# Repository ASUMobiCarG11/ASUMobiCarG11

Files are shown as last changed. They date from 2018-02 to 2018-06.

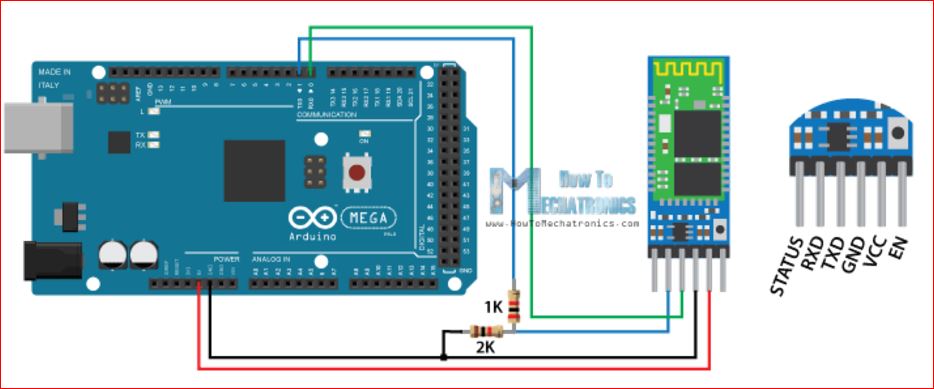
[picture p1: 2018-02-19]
bluetooth Module installation.JPG

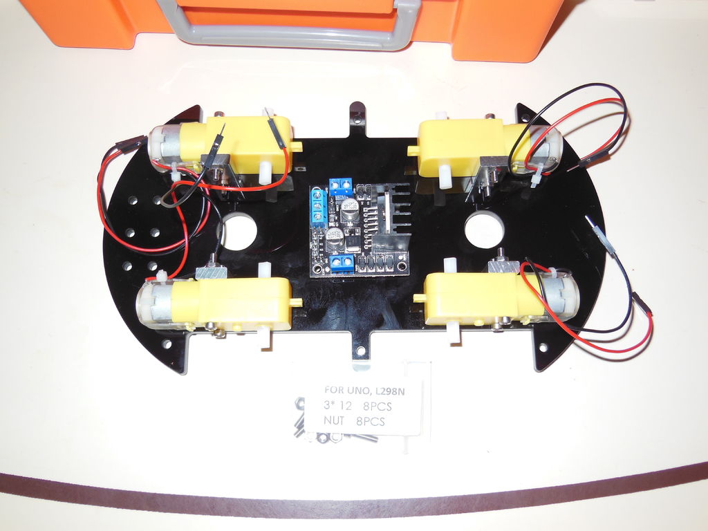
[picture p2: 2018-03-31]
Car installation step by step/installing mototr driver 1.jpg

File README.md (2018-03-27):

# ASUMobiCarG11
DESCRIPTION: 

It is required to develop a Mobile Controlled Car. The car allow easy driving with obstacles avoidance, accurate movement, line tracking.
A simple android application is used to control the car.

The project is submitted to DR/ Mohamed Sobh / Control Componenets course / Faculty of Engineering / Ain Shams Universty 

Team Members :

Omar Mohamed Ali  

Omar Nasr el Din

Omar Hesham 

Kareem Salah

Martin Joseph

Mark Youssef

Mario Hany 

Micheal Ashraf

Fatma abdelmoniem

Fayrouz Niazy 

CAR Videos :https://drive.google.com/folderview?id=14SdS284a--CmgsWrzYH-oOBZbFa_0wmK

#For Contact : 
    Github :  
    
    OmarNasrEldeen

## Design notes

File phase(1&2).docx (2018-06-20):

-project name : mobicar project

****************************************************

-the purpose:

- in our project we want to develop a Mobile Controlled Car. The car allow easy driving with obstacles avoidance, accurate movement, line tracking.

*****************************************************

-project contants:

*our project contants from 2 steps:

i.Easy Driving Application:

-Our purpose that user can control car movement (in all directions) using mobile

<Using Bluetooth module> and the car should be able to avoid obstacles <using ultrasonic>.

ii.Line Tracking Application:

-our purpose that can follow the line when it placed over the track

<using line follow sensor>

****************************************************************************

-First step in details:

We use: Arduino Uno - motor driver - Bluetooth module - body of car –

3 batteries - ultrasonic

-at first meeting : we connect motor driver with motors of the car body and connect it with

arduino according the code of arduino,we connect the Bluetooth module with arduino

,and supply all circuit with batteries . After many tries to make sure our code and our

connections, we use a Bluetooth app to control the car to make sure that it can move in

all direction according the app .

--this picture shows the all connections:

***********************************************************************************

-at second meeting : we maked sure that the previous step was Successful .and continue

our connections , connect the ultra-sonic with arduino and try to move a car , at this time

we faced our first problem which was that we find two wheel move but the other don't

move we think that was the mistake in code ,we check it step by step to discover the

mistake but we found that the code is completely correct and discovered that problem

happen when we connect all component with each other ,so we found out that problem

of supply so we recharged our batteries and try again ,we found out this problem

disappear.

--this link of the video of the car motion with avoid obstacles:

https://drive.google.com/folderview?id=14SdS284a--CmgsWrzYH-oOBZbFa_0wmK

*************************************************************************************

second step in details:

we use : all the previous components +3 line follower sensor

- At first meeting : we connect the 3 sensors with the Arduino according the code , then we make sure that all the connections are right , then we tests the code and fixed it as we found a problems with it and the line follower wasn’t working well .
- At the second meeting : we checked that the the connections and the code are working well , but we found a problem “ the places that we put the sensors on it were not making the car follow the directions well “ – so we tried to fix this and after many tries it works , and we check that the car follows the tracks well as we make tracks for it and it works well.
- At the third meeting : we prepared for the track and draw it on the 2x2m white sheets and the line thickness was 2mm , we started to work on it and put the car to follow the track , but the car went out of the track and we tried to find the problem in the car and after many tries it didn’t work , so we announce the doctor that that track thickness makes problem with the car and he tells us to work on another thickness.
- At the 4th meeting : we made the track on the new thickness and tried to test it with the car and it worked , we shot the video for the car and then we upload it .

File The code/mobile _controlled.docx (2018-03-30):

#include <AFMotor.h>

| AF_DCMotor motor1(1);
| AF_DCMotor motor2(2);
| AF_DCMotor motor3(3);
| AF_DCMotor motor4(4);
| char bt='S';
| void setup()
| {
| Serial.begin(38400);
| motor1.setSpeed(255);
| motor2.setSpeed(255);
| motor3.setSpeed(255);
| motor4.setSpeed(255);
| Stop();
| }
| void loop() {
| bt=Serial.read();
| if(bt=='F')
| {
| forward();
| }
| if(bt=='B')
| {
| backward();
| }
| if(bt=='L')
| {
| left();
| }
| if(bt=='R')
| {
| right();
| }
| if(bt=='S')
| {
| Stop();
| }
| }
| void forward()
| {
| motor1.run(FORWARD);
| motor2.run(FORWARD);
| motor3.run(FORWARD);
| motor4.run(FORWARD);
| }
| void backward()
| {
| motor1.run(BACKWARD);
| motor2.run(BACKWARD);
| motor3.run(BACKWARD);
| motor4.run(BACKWARD);
| }
| void left()
| {
| motor1.run(FORWARD);
| motor2.run(FORWARD);
| motor3.run(BACKWARD);
| motor4.run(BACKWARD);
| }
| void right()
| {
| motor1.run(BACKWARD);
| motor2.run(BACKWARD);
| motor3.run(FORWARD);
| motor4.run(FORWARD);
| }
| void Stop()
| {
| motor1.run(RELEASE);
| motor2.run(RELEASE);
| motor3.run(RELEASE);
| motor4.run(RELEASE);
| }

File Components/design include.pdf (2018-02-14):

Design i just attach in group included The following:

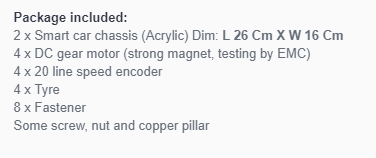
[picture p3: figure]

## PRICE :250 LE

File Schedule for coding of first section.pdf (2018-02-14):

## Schedule for coding of first section

## Schedule

Week 2 | Designing of car functionality
Week 3 | Coding of DC motors
Week 4 | Coding of ultrasonic sensor
Week 5 | Coding of servo motor
Week 6 | Testing and debugging

debugging

coding

Design

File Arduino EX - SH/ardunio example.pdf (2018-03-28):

Programming
code for
Receiver
part::
const int trigPin = 9; const int echoPin = 10; // defines variables
long duration;
int distance, Pdistance; void setup()
{
pinMode(trigPin, OUTPUT); // Sets the trigPin as an Output pinMode(echoPin, INPUT); // Sets the echoPin as an Input Serial.begin(9600); // Starts the serial communication
}
void loop()
{
Pdistance=distance;
Calc();
distance= duration*0.034;
if (Pdistance==distance || Pdistance==distance+1 || Pdistance==distance-1 )

{
Serial.print("Measured Distance: ");
Serial.println(distance/2);
}
//Serial.print("Distance: "); //Serial.println(distance/2); delay(500);
}
void Calc()
{
duration=0;
Trigger_US();
while (digitalRead(echoPin)==HIGH); delay(2);
Trigger_US();
duration = pulseIn(echoPin, HIGH); }
void Trigger_US()
{
// Fake trigger the US sensor digitalWrite(trigPin, HIGH); delayMicroseconds(10); digitalWrite(trigPin, LOW);
}
// Programming code for Transmitter part:: // defines pins numbers
const int trigPin = 9;
const int echoPin = 10; // defines variables
long duration;
int distance;
void setup()
{

pinMode(trigPin, OUTPUT); // Sets the trigPin as an Output pinMode(echoPin, INPUT); // Sets the echoPin as an Input Serial.begin(9600); // Starts the serial communication
}
void loop()
{
// Sets the trigPin on HIGH state for 10 micro seconds digitalWrite(trigPin, HIGH);
delayMicroseconds(10);
digitalWrite(trigPin, LOW); delay(2);
}

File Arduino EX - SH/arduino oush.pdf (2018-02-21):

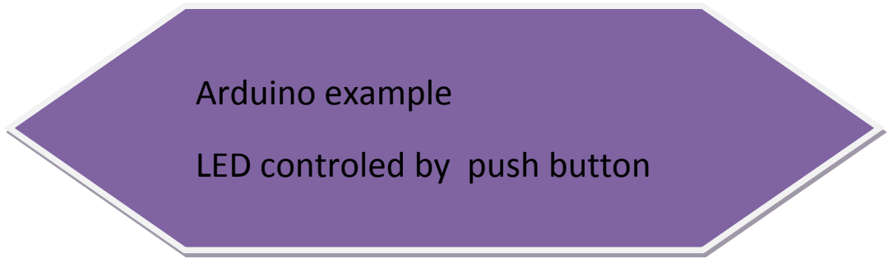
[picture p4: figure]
Arduino example; LED controled by push button
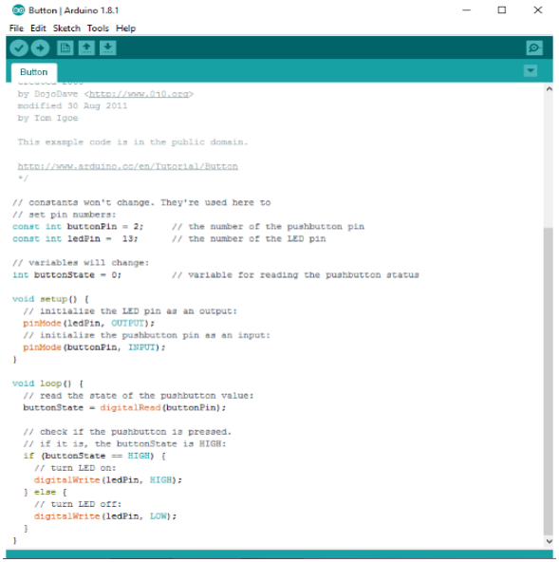
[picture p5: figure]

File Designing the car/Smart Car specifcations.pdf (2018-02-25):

# Smart Car

# ASUMobiCarG11

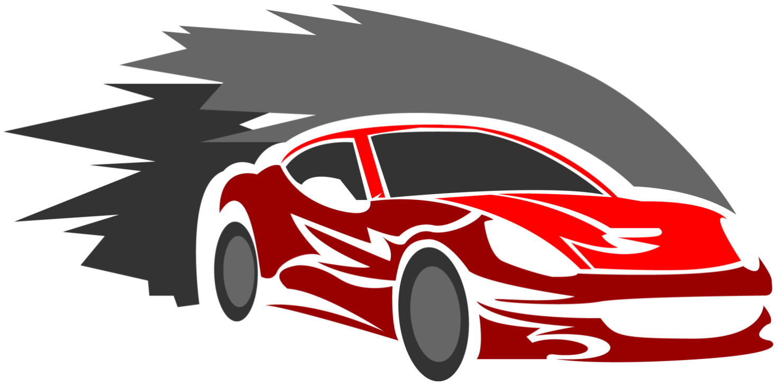
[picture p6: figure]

# It’s time to control

# Team members

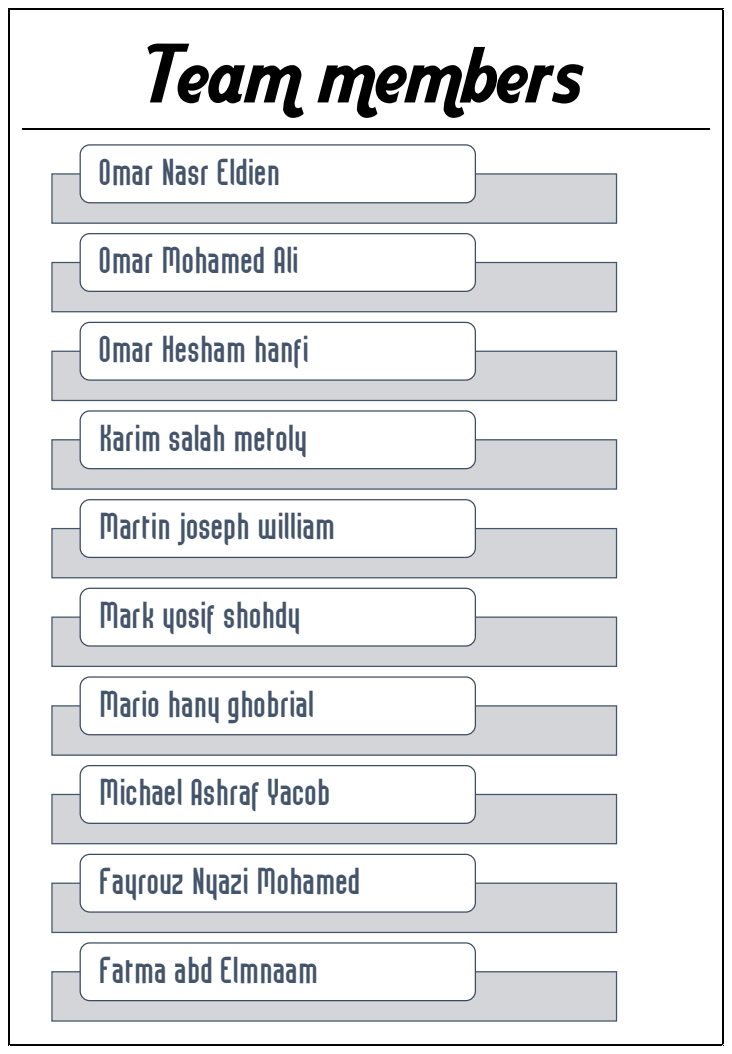
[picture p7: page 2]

Omar Nasr Eldien

Omar Mohamed Ali

Omar Hesham hanfi

Karim salah metoly

Martin joseph william

Mark yosif shohdy

Mario hany ghobrial

Michael Ashraf Yacob

Fayrouz Nyazi Mohamed

Fatma abd Elmnaam

# Car specifications

# 1- Bluetooth control

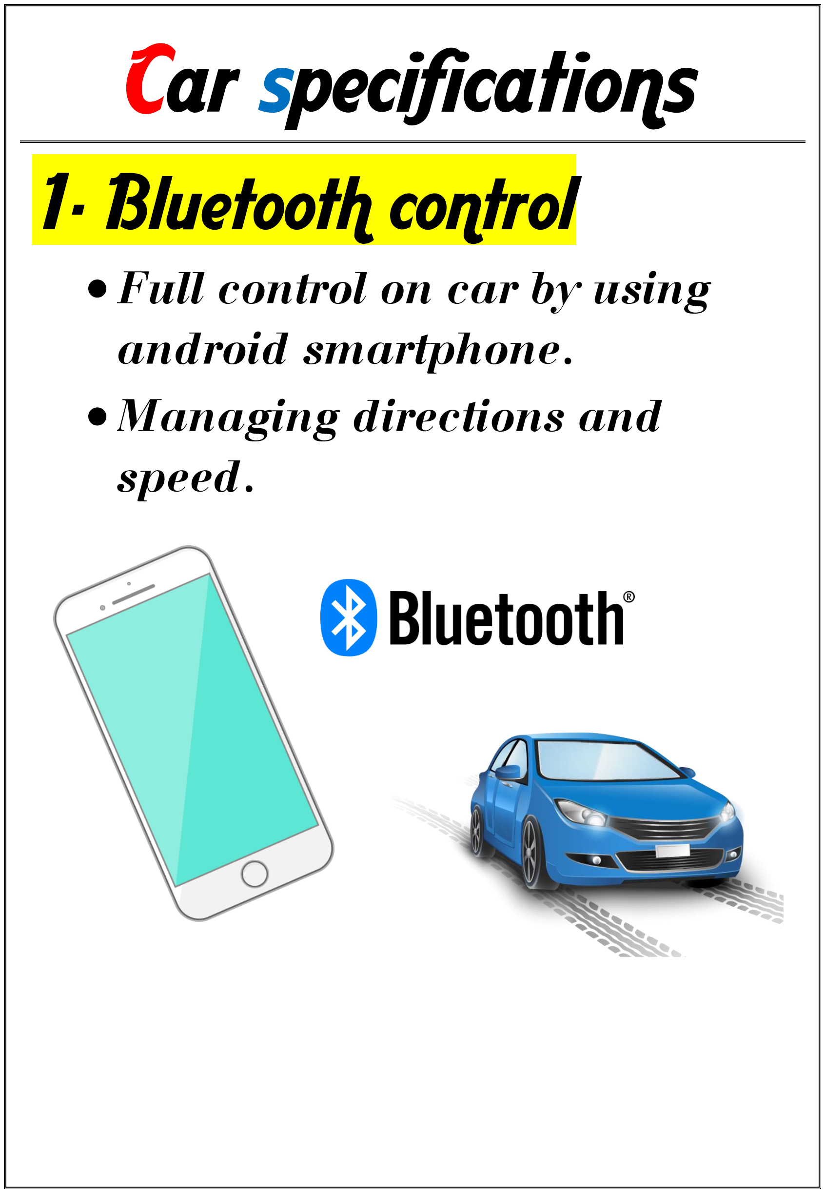
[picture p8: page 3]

•

•

# 2.Avoiding Obstacles

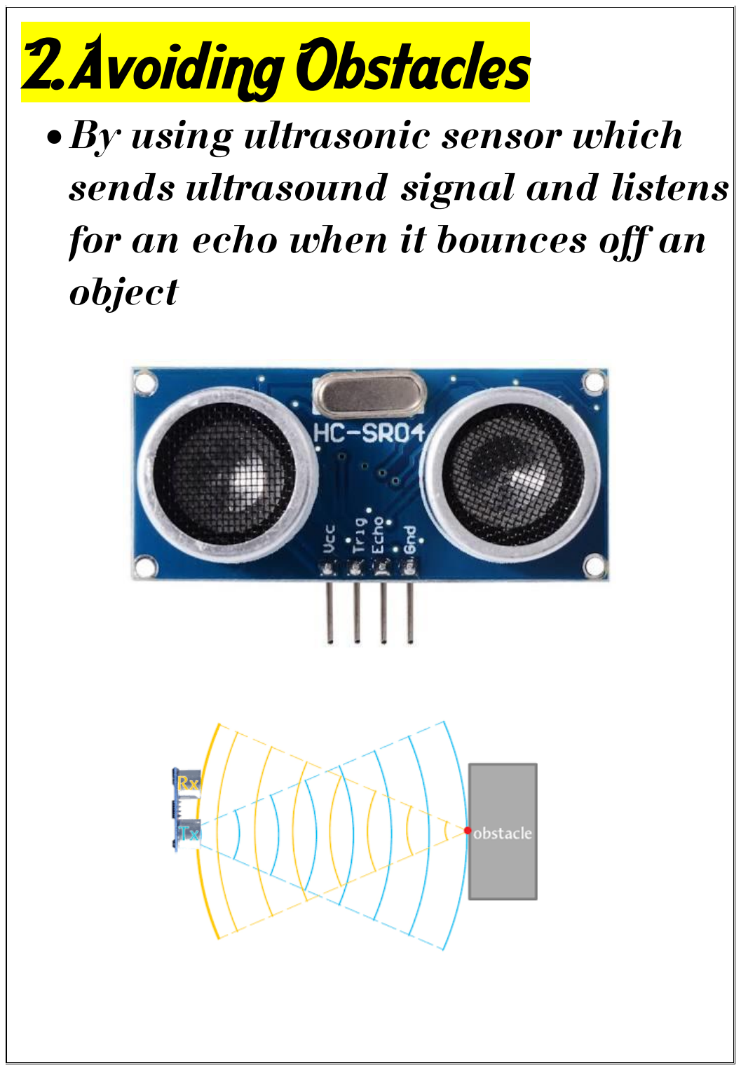
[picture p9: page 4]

•

# 3.Line tracking

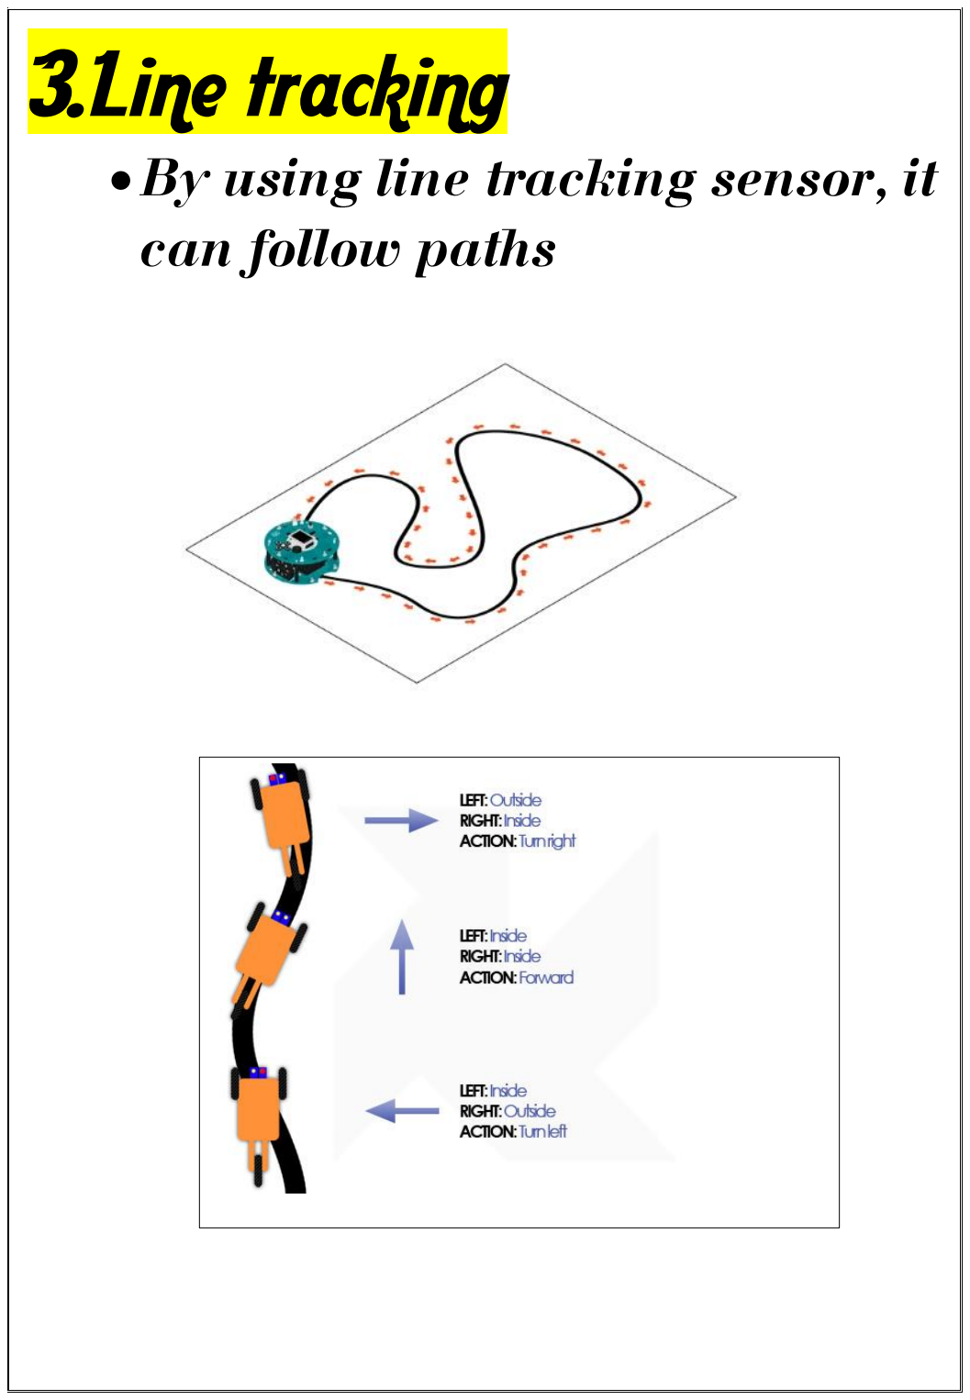
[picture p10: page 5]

•

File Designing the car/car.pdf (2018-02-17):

Car has been delivered :D

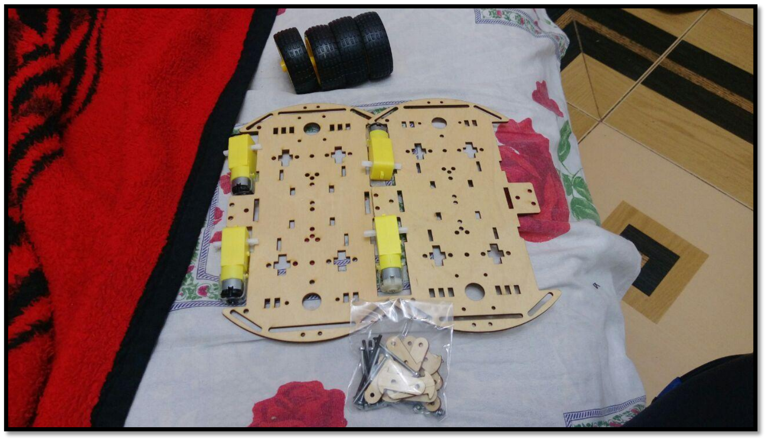
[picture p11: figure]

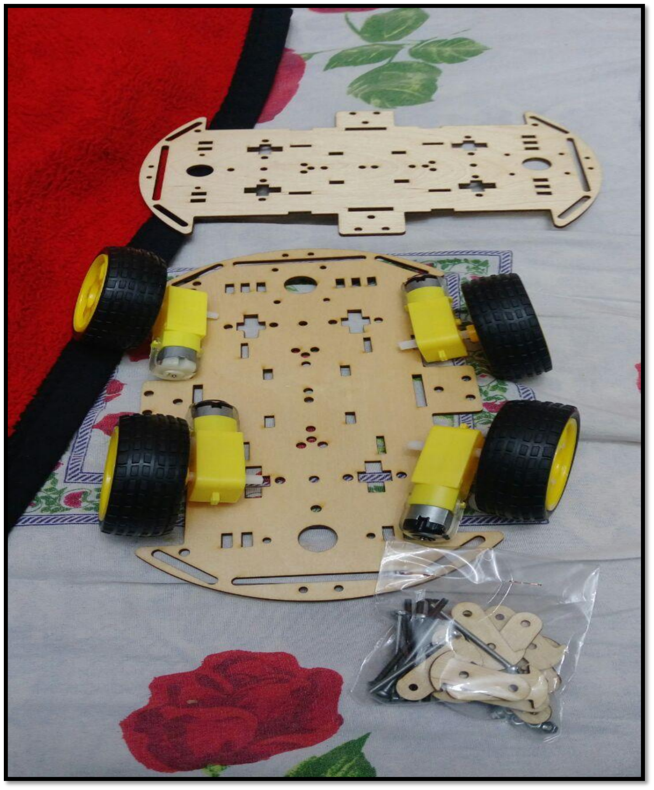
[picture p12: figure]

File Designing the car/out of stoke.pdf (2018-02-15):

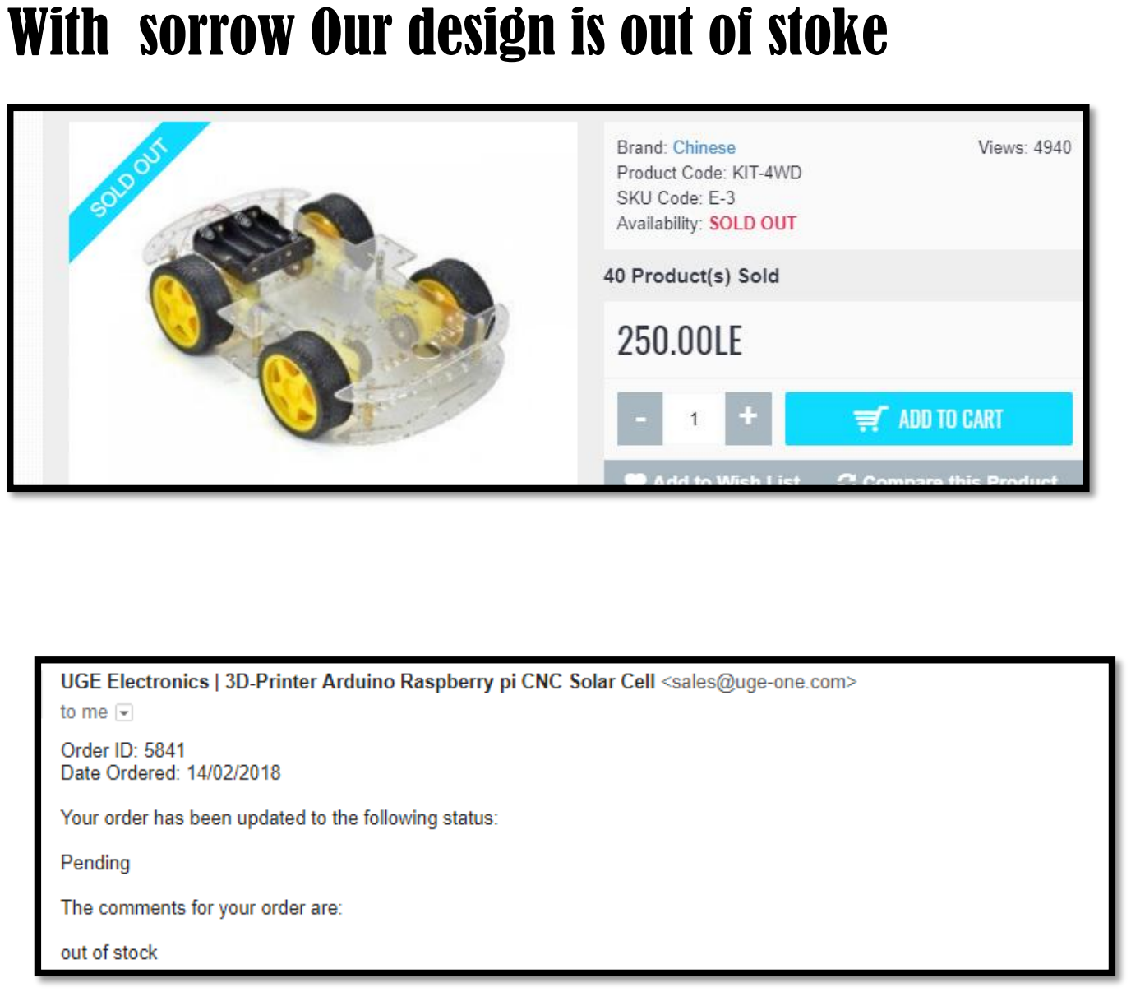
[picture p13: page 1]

With sorrow Our design is out of stoke

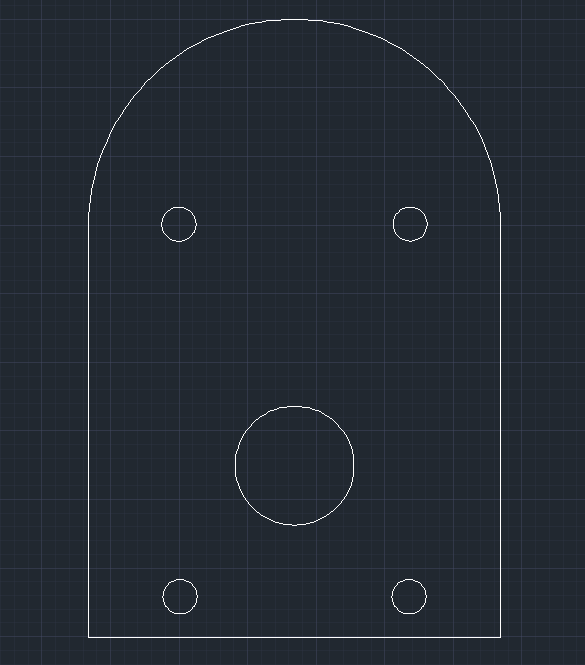
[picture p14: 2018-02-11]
Designing the car/re-car des 1.png

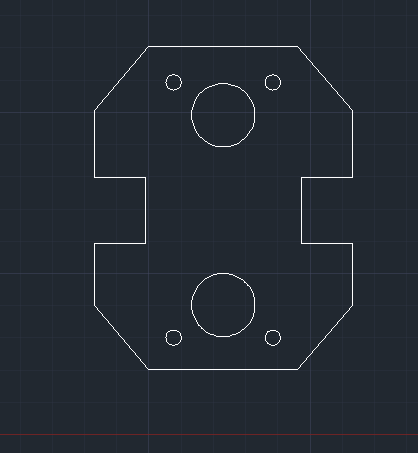
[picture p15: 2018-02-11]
Designing the car/re-car des 2.png

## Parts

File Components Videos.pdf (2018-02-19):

I watched this videos

Motor Driver : control DC Motors with Arduino + L298N

https://www.youtube.com/watch?v=kv-9mxVaVzE

Bluetooth module hc-05 with Arduino

https://www.youtube.com/watch?v=-z_0aU8VHzk

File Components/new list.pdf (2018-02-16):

The needed List (16/2)

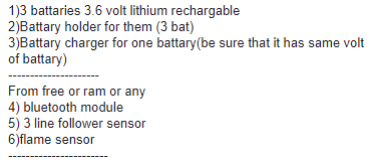
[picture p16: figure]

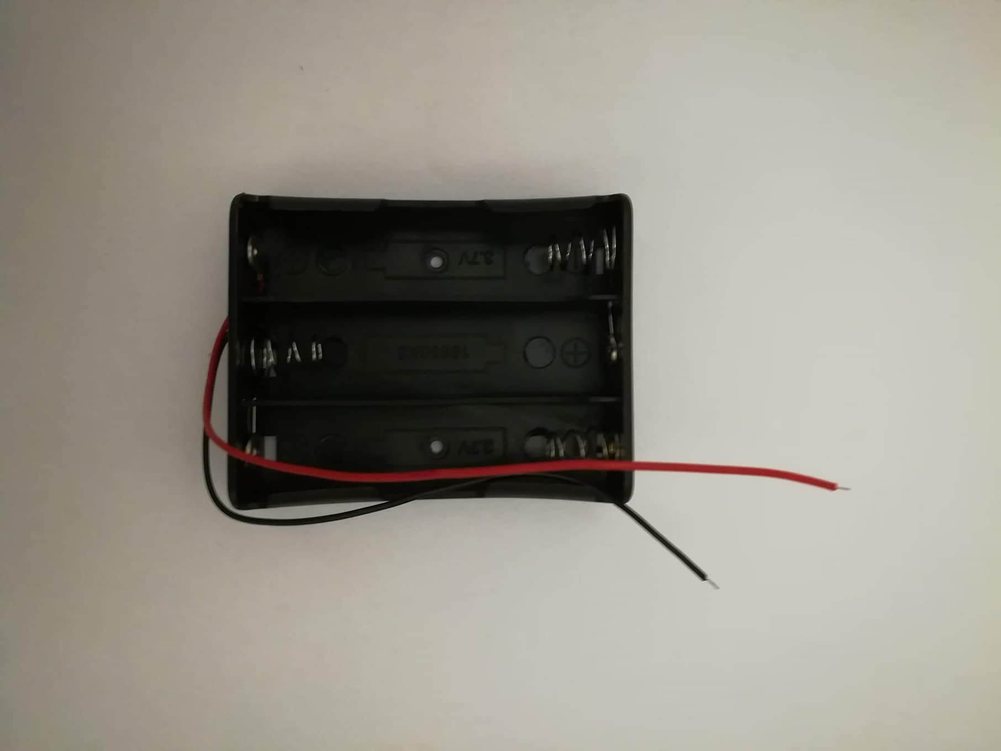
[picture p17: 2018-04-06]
Components/Battery Holder.jpg

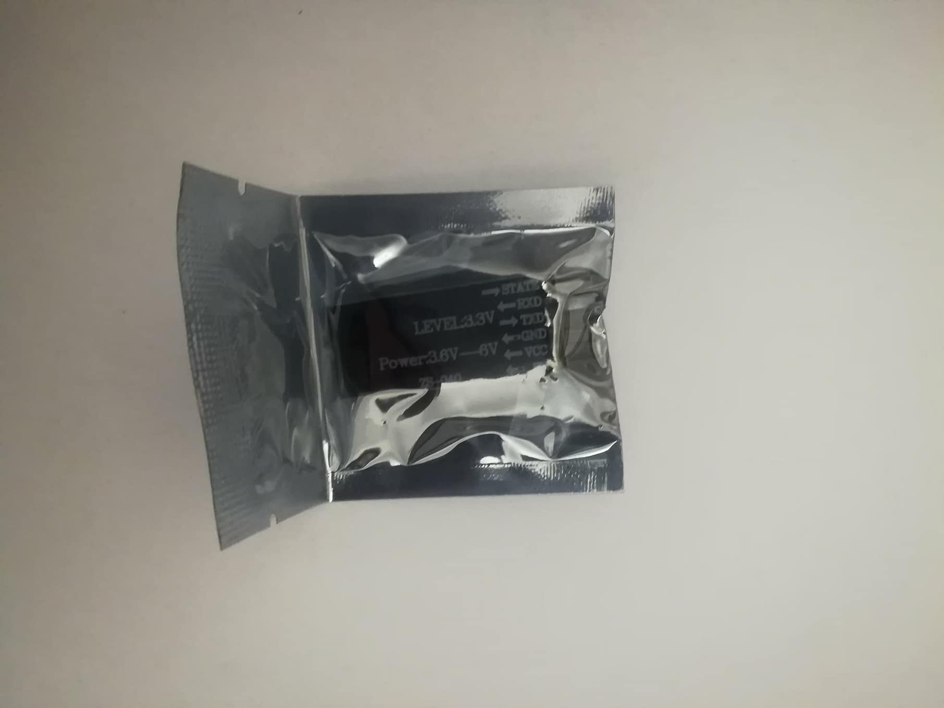
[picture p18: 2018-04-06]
Components/Bluetooth Module HC05.jpg

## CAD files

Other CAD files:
car model.dwg

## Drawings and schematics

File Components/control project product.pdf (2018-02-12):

# Control Project

# Mob Car

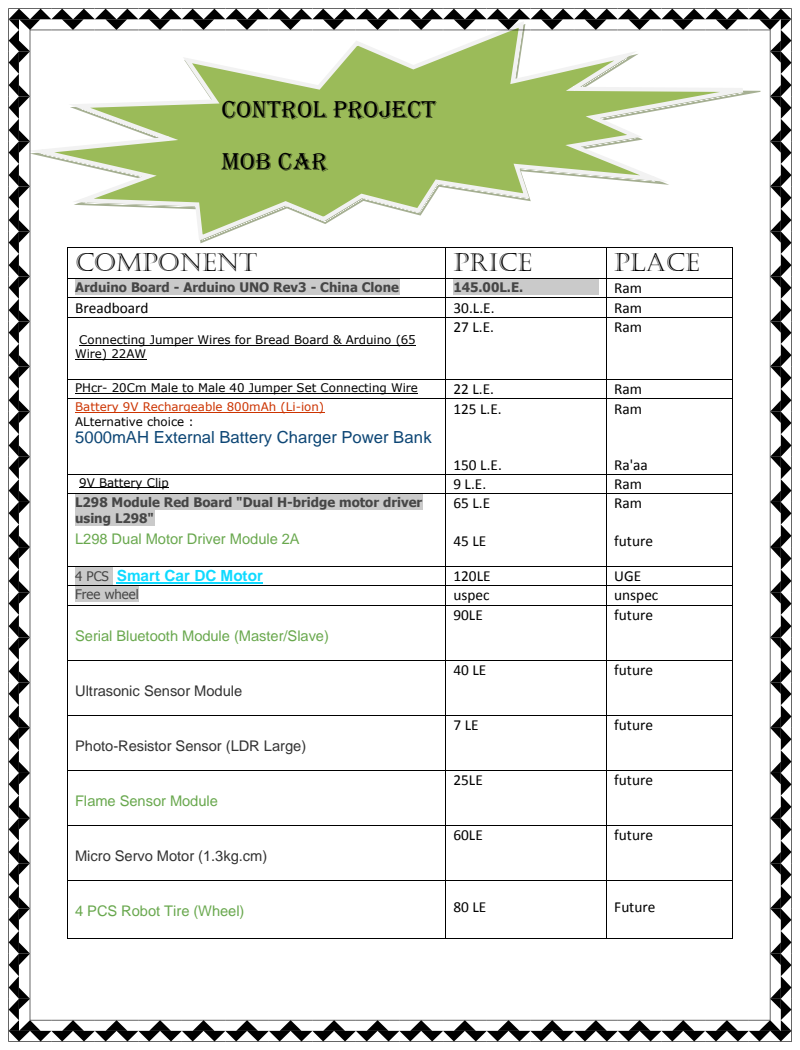
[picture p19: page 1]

Component | price | Place

Arduino Board - Arduino UNO Rev3 - China Clone | 145.00L.E. | Ram
Breadboard | 30.L.E. | Ram
Connecting Jumper Wires for Bread Board & Arduino (65 Wire) 22AW (http://ram-e-shop.com/oscmax/catalog/product_info.php?cPath=37&products_id=3183) | 27 L.E. | Ram

PHcr- 20Cm Male to Male 40 Jumper Set Connecting Wire (http://ram-e-shop.com/oscmax/catalog/product_info.php?cPath=37&products_id=3333) | 22 L.E. | Ram
Battery 9V Rechargeable 800mAh (Li-ion) (http://ram-e-shop.com/oscmax/catalog/product_info.php?cPath=72_74&products_id=1125) ALternative choice : 5000mAH External Battery Charger Power Bank | 521 L.E. 150 L.E. | Ram Ra'aa

9V Battery Clip (http://ram-e-shop.com/oscmax/catalog/product_info.php?cPath=72_75&products_id=615) | 9 L.E. | Ram
L298 Module Red Board "Dual H-bridge motor driver using L298" L298 Dual Motor Driver Module 2A (https://store.fut-electronics.com/collections/dc-motor-driver/products/l298-dual-motor-driver-module-2a) | 65 L.E 45 LE | Ram future

4 PCS Smart Car DC Motor (https://uge-one.com/robotics-motors/dc-motors/smart-car-dc-motor.html) | 120LE | UGE
Free wheel | uspec | unspec
Serial Bluetooth Module (Master/Slave) (https://store.fut-electronics.com/collections/bluetooth/products/serial-bluetooth-module-master-slave) | 99LE | future

Ultrasonic Sensor Module (https://store.fut-electronics.com/collections/light-infrared-sound/products/ultrasonic-sensor-module) | 40 LE | future

Photo-Resistor Sensor (LDR Large) (https://store.fut-electronics.com/collections/light-infrared-sound/products/photo-resistor-sensor-ldr-large) | 7 LE | future

Flame Sensor Module (https://store.fut-electronics.com/collections/light-infrared-sound/products/flame-sensor-module) | 25LE | future

Micro Servo Motor (1.3kg.cm) (https://store.fut-electronics.com/collections/servo-motors/products/micro-servo-motor-1-3kg-cm) | 60LE | future

4 PCS Robot Tire (Wheel) (https://store.fut-electronics.com/products/robot-tire-wheel) | 80 LE | Future

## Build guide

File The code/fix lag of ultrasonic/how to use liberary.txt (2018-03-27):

https://www.youtube.com/watch?v=EtoKLtI5lsg

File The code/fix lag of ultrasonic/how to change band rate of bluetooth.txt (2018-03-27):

https://www.youtube.com/watch?v=zoJUAjW3vQ0

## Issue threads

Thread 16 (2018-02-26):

we have two choices : either melting solider from motor tomorrow and working thursday , OR , using fatma's motor tomorrow .

omaralam96, 2018-02-26:

Closed 2018-02-27.

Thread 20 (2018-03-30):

re-organizing /n : shbab ana shayf mafesh 7ad mas7 eli hoa kan menzo fi el master wi 3amalo re-upload fi el file el 5as beh ?!!!! msh yala ba2a wla eah :D

omaralam96, 2018-03-30:

omaralam96, 2018-03-31:
hoa ento moto ?!!!!!!!!!!! :smile:
ma7ad yirod ya shbab :smiley:
@fatmaabdelmoniem @OmarNasrELdeen @kareem1002009 @omarhesham1997 @martinjowi

MichaelAshrafYacop, 2018-03-31:
I did that alam

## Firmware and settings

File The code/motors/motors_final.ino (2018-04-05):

int MotorLF = 9 ; // two left wheels move forward
int MotorRF = 6; // two right wheels move forward
int MotorLB = 10; // two left wheels move backward
int MotorRB = 5; // two right wheels move Backward
int speedState;
char command;  //bluetooth state

void setup() {
  Serial.begin(9600);
  pinMode(MotorLF, OUTPUT);
  pinMode(MotorRF, OUTPUT);
  pinMode(MotorLB, OUTPUT);
  pinMode(MotorRB, OUTPUT);
}
void Stop() // stop car
{
  analogWrite(MotorLF,0);
  analogWrite(MotorRF,0);
  analogWrite(MotorLB,0);
  analogWrite(MotorRB,0);
}
void forward() // move car forward 
{
  analogWrite(MotorLF,speedState);
  analogWrite(MotorRF,speedState);
  analogWrite(MotorLB,0);
  analogWrite(MotorRB,0);
}

void moveForwardLeft()
{
  analogWrite(MotorLF,speedState/2);
  analogWrite(MotorRF,speedState);
  analogWrite(MotorLB,0);
  analogWrite(MotorRB,0);
  
}

void moveForwardRight()
{
  analogWrite(MotorLF,speedState);
  analogWrite(MotorRF,speedState/2);
  analogWrite(MotorLB,0);
  analogWrite(MotorRB,0);
  
}

void backward() //move car backward
{
  analogWrite(MotorLF,0);
  analogWrite(MotorRF,0);
  analogWrite(MotorLB,speedState);
  analogWrite(MotorRB,speedState);
}

void moveBackwardLeft()
{
  analogWrite(MotorLF,0);
  analogWrite(MotorRF,0);
  analogWrite(MotorLB,speedState/2);
  analogWrite(MotorRB,speedState);
  
}

void moveBackwardRigth()
{
 analogWrite(MotorLF,0);
  analogWrite(MotorRF,0);
  analogWrite(MotorLB,speedState);
  analogWrite(MotorRB,speedState/2);
}

void left() //move car to left
{
  analogWrite(MotorLF,0);
  analogWrite(MotorRF,speedState);
  analogWrite(MotorLB,speedState);
  analogWrite(MotorRB,0);
}

void right() //move car to right
{
  analogWrite(MotorLF,speedState);
  analogWrite(MotorRF,0);
  analogWrite(MotorLB,0);
  analogWrite(MotorRB,speedState);
}

void setSpeed (int x) {
  speedState = map(x, 0, 100, 0, 255);
}
void loop() {
  if (Serial.available() > 0) {
    command = Serial.read();
    Serial.println(command);

    //******************Controls*****************
    if (command == '0') {
      setSpeed(0);
    }
    else if (command == '1') {
      setSpeed(10);
    }
    else if (command == '2') {
      setSpeed(20);
    }
    else if (command == '3') {
      setSpeed(30);
    }
    else if (command == '4') {
      setSpeed(40);
    }
    else if (command == '5') {
      setSpeed(50);
    }
    else if (command == '6') {
      setSpeed(60);
    }
    else if (command == '7') {
      setSpeed(70);
    }
    else if (command == '8') {
      setSpeed(80);
    }
    else if (command == '9') {
      setSpeed(90);
    }
    else if (command == 'q') {
      setSpeed(100);
    }
    // moving forward if distance >20
    else if (command == 'F') {
      forward();
    }
    // move Forward Left if distance >20
    else if (command == 'G') {
      moveForwardLeft();
    }
    // move Forward Right if distance >20
    else if (command == 'I') {
      moveForwardRight();
    }
    // moving backward
    else if (command == 'B') {
      backward();
    }
    // moving back left
    else if (command == 'H') {
      moveBackwardLeft();
    }
    // moving back right
    else if (command == 'J') {
      moveBackwardRigth();
    }
    // moving left
    else if (command == 'L') {
      left();
    }
    // moving right
    else if (command == 'R') {
      right();
    }
    // stop
    else if (command == 'S') {
      Stop();
    }
  }
}

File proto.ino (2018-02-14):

include <Servo.h>
Servo myservo; // create servo object to control a servo
int angle = 0;
/* * Created by Vasilakis Michalis // 12-12-2014 ver.1
 * Project: Control RC Car via Bluetooth with Android Smartphone
 * http://www.ardumotive.com/arduino-car
 * More information at www.ardumotive.com
 */
 
//L293 Connection   
  const int motorURF  = 5;  // Pin  2 of L293    omar upper right
  const int motorURB = 6;  // Pin  7 of L293    omar upper left
  const int motorULF  = 10; // Pin 10 of L293    omar lower right
  const int motorULB = 9;  // Pin 14 of L293   omar lower left 
  const int motorLRF  = 50;  // Pin  2 of L293    omar upper right zawdt 0 bs 3n ely fo2
  const int motorLRB = 60;  // Pin  7 of L293    omar upper left
  const int motorLLF  = 100; // Pin 10 of L293    omar lower right
  const int motorLLB = 90;  // Pin 14 of L293   omar lower left 
//Leds connected to Arduino UNO Pin 12
  const int lights  = 12;
//Buzzer / Speaker to Arduino UNO Pin 3
  const int buzzer = 3 ;   
//Bluetooth (HC-06 JY-MCU) State pin on pin 2 of Arduino
  const int BTState = 2;
//Calculate Battery Level
  const float maxBattery = 8.0;// Change value to your max battery voltage level! 
  int perVolt;                 // Percentage variable 
  float voltage = 0.0;         // Read battery voltage
  int level;
// Use it to make a delay... without delay() function!
  long previousMillis = -1000*10;// -1000*10=-10sec. to read the first value. If you use 0 then you will take the first value after 10sec.  
  long interval = 1000*10;       // interval at which to read battery voltage, change it if you want! (10*1000=10sec)
  unsigned long currentMillis;   //unsigned long currentMillis;
//Useful Variables
  int i=0;
  int j=0;
  int state;
  int vSpeed=200;     // Default speed, from 0 to 255

void setup() {
  myservo.write(90);
    // Set pins as outputs:
    pinMode(motorA1, OUTPUT);
    pinMode(motorA2, OUTPUT);
    pinMode(motorB1, OUTPUT);
    pinMode(motorB2, OUTPUT);
    pinMode(lights, OUTPUT); 
    pinMode(BTState, INPUT);    
    // Initialize serial communication at 9600 bits per second:
    Serial.begin(9600);
}
 
void loop() {
  //Stop car when connection lost or bluetooth disconnected
     if(digitalRead(BTState)==LOW) { state='S'; }

  //Save income data to variable 'state'
    if(Serial.available() > 0){     
      state = Serial.read();   
    }
  
  //Change speed if state is equal from 0 to 4. Values must be from 0 to 255 (PWM)
    if (state == '0'){
      vSpeed=0;}
    else if (state == '1'){
      vSpeed=100;}
    else if (state == '2'){
      vSpeed=180;}
    else if (state == '3'){
      vSpeed=200;}
    else if (state == '4'){
      vSpeed=255;}
 	  
  /***********************Forward****************************/
  //If state is equal with letter 'F', car will go forward!
    if (state == 'F') {
    	analogWrite(motorA1, vSpeed); analogWrite(motorA2, vSpeed);
        analogWrite(motorB1, vSpeed);      analogWrite(motorB2, vSpeed); 
    }
  /**********************Forward Left************************/
  //If state is equal with letter 'G', car will go forward left
    else if (state == 'G') {
       
myservo.write(45); //delay(20);
    	analogWrite(motorA1, vSpeed); analogWrite(motorA2, vSpeed);  
        analogWrite(motorB1, vSpeed);    analogWrite(motorB2, vSpeed); 
    }
  /**********************Forward Right************************/
  //If state is equal with letter 'I', car will go forward right
    else if (state == 'I') {
      
myservo.write(135); //delay(20);
      	analogWrite(motorA1, vSpeed); analogWrite(motorA2, vSpeed); 
        analogWrite(motorB1, vSpeed);      analogWrite(motorB2, vSpeed); 
    }
  /***********************Backward****************************/
  //If state is equal with letter 'B', car will go backward
    else if (state == 'B') {
    	analogWrite(motorA1, 0);   analogWrite(motorA2, vSpeed); 
        analogWrite(motorB1, 0);   analogWrite(motorB2, 0); 
    }
  /**********************Backward Left************************/
  //If state is equal with letter 'H', car will go backward left
    else if (state == 'H') {
    	analogWrite(motorA1, 0);   analogWrite(motorA2, vSpeed); 
        analogWrite(motorB1, 200); analogWrite(motorB2, 0); 
    }
  /**********************Backward Right************************/
  //If state is equal with letter 'J', car will go backward right
    else if (state == 'J') {
    	analogWrite(motorA1, 0);   analogWrite(motorA2, vSpeed); 
        analogWrite(motorB1, 0);   analogWrite(motorB2, 200); 
    }
  /***************************Left*****************************/
  //If state is equal with letter 'L', wheels will turn left
    else if (state == 'L') {
    	analogWrite(motorA1, 0);   analogWrite(motorA2, 0); 
        analogWrite(motorB1, 200); analogWrite(motorB2, 0); 
    }
  /***************************Right*****************************/
  //If state is equal with letter 'R', wheels will turn right
    else if (state == 'R') {
    	analogWrite(motorA1, 0);   analogWrite(motorA2, 0); 
        analogWrite(motorB1, 0);   analogWrite(motorB2, 200); 		
    }
  /************************Lights*****************************/
  //If state is equal with letter 'W', turn leds on or of off
    else if (state == 'W') {
      if (i==0){  
         digitalWrite(lights, HIGH); 
         i=1;
      }
      else if (i==1){
         digitalWrite(lights, LOW); 
         i=0;
      }
      state='n';
    }
  /**********************Horn sound***************************/
  //If state is equal with letter 'V', play (or stop) horn sound
    else if (state == 'V'){
      if (j==0){  
         tone(buzzer, 1000);//Speaker on 
         j=1;
      }
      else if (j==1){
         noTone(buzzer);    //Speaker off 
         j=0;
      }
      state='n';  
    }
  /************************Stop*****************************/
  //If state is equal with letter 'S', stop the car
    else if (state == 'S'){
        analogWrite(motorA1, 0);  analogWrite(motorA2, 0); 
        analogWrite(motorB1, 0);  analogWrite(motorB2, 0);
    }
  /***********************Battery*****************************/
  //Read battery voltage every 10sec.
    currentMillis = millis();
    if(currentMillis - (previousMillis) > (interval)) {
       previousMillis = currentMillis; 
       //Read voltage from analog pin A0 and make calibration:
       voltage = (analogRead(A0)*5.015 / 1024.0)*11.132;
       //Calculate percentage...
       perVolt = (voltage*100)/ maxBattery;
       if      (perVolt<=75)               { level=0; }
       else if (perVolt>75 && perVolt<=80) { level=1; }    //        Battery level
       else if (perVolt>80 && perVolt<=85) { level=2; }    //Min ------------------------   Max
       else if (perVolt>85 && perVolt<=90) { level=3; }    //    | 0 | 1 | 2 | 3 | 4 | 5 | >
       else if (perVolt>90 && perVolt<=95) { level=4; }    //    ------------------------
       else if (perVolt>95)                { level=5; }
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

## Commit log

2018-02-14 Add files via upload
    design by buttons step(1)
2018-02-14 prototype code
2018-02-17 coding of motors using AFMotor library
    Is there any comments
2018-02-18 Create L
    Some links explaining how to connect L298N Dual H-Bridge Motor Driver to Arduino & DC Motors.
2018-02-21 Arduino example:
    ultrasonic receiving and transmitting code
2018-02-21 Ardunio Ex On/Off Push button
2018-02-23 Rename mark youssef/Sheet__1_Q_1_.ino to Arduino EX - SH/Sheet__1_Q_1_.ino
2018-02-23 Rename mark youssef/Sheet__1_Q_2_.ino to Arduino EX - SH/Sheet__1_Q_2_.ino
2018-02-23 Rename sketch_feb12a.ino to The code/motor code version 1.ino
2018-02-25 coding of motors
    full control of car
2018-02-25 coding of motors using AFMotor library
2018-02-25 Rename motors.ino to motors version 2.ino
2018-03-05 code of ultrasonic
    working fine
2018-03-05 ultrasonic with servo
2018-03-09 servo__ultrasonic ver 2
2018-03-27 Create ultrasonic
2018-03-27 Create ultrasonic codes
2018-03-27 Rename ultrasonic codes to fixing lag of ultrasonic
2018-03-27 Rename The code/servo__ultrasonic ver 2.ino to The code/ultrasonic/servo__ultrasonic ver 2.ino
2018-03-27 Rename The code/ultrasonic with servo.ino to The code/ultrasonic/ultrasonic with servo.ino
2018-03-27 Rename The code/ultrasonic.ino to The code/ultrasonic/ultrasonic.ino
2018-03-27 Rename The code/ultrasonic___servo_code.ino to The code/ultrasonic/ultrasonic___servo_code.ino
2018-03-28 Add files via upload
    Ultrasonic transmited and reciver
2018-03-28 On/off switch ex
2018-03-30 Add files via upload
    charger charge the battery
2018-03-30 Add files via upload
    the body with 4 motors and wheeles
2018-03-31 installing arduino
2018-03-31 installing motor driver i
2018-03-31 installing motor driver ii
2018-04-06 Add files via upload
    3 Line follower sensors
    35 LE each
    from free electronics
2018-04-06 Add files via upload
    Battery Holder - 3 cell
    15 LE
    from Free electronics
2018-04-09 Final case 1
2018-04-09 final case 2
